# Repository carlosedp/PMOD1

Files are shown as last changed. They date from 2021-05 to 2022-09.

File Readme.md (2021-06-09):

# PMOD1 - RingPush module

This repository hosts all data related to PMOD1, a PMOD module with a LED ring and a rotary encoder with push button. Always use the latest version of the PCB.

## PCB 3D View:

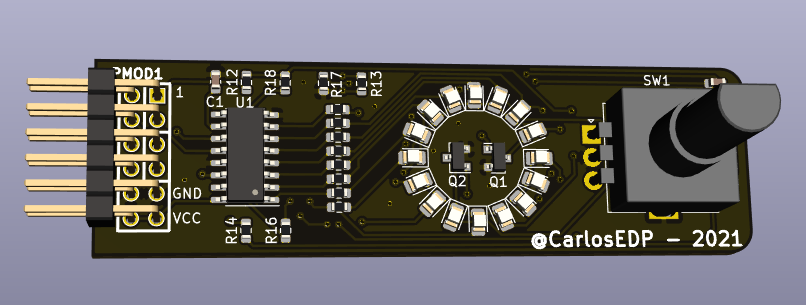
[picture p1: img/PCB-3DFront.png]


## Schematic

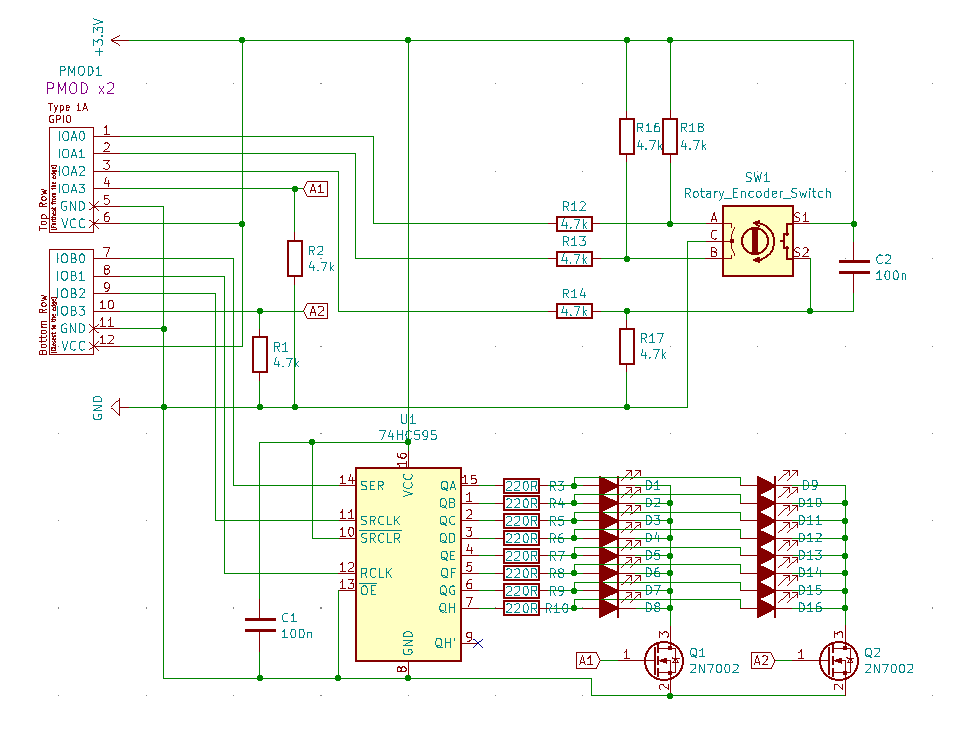
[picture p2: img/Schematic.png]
schematic


## BOM

Id|Designator|Package|Quantity|Designation|
----|------------|---------|----------|-------------|
1|U1|SOIC-16_3.9x9.9mm_P1.27mm|1|74HC595|||
2|PMOD1|pmod_pin_array_6x2|1|PMOD-Device-x2-Type-1A-GPIO|||
3|SW1|RotaryEncoder_Alps_EC11E-Switch_Vertical_H20mm|1|Rotary_Encoder_Switch|||
4|R1,R2,R12,R13,R14,R16,R17,R18|R_0603_1608Metric_Pad0.98x0.95mm_HandSolder|8|4.7k|||
5|C1,C2|C_0603_1608Metric_Pad1.08x0.95mm_HandSolder|2|100n|||
6|D1,D2,D3,D4,D5,D6,D7,D8,D9,D10,D11,D12,D13,D14,D15,D16|LED_0805_2012Metric_Pad1.15x1.40mm_HandSolder|16|LED_ALT|||
7|R3,R4,R5,R6,R7,R8,R9,R10|R_0603_1608Metric_Pad0.98x0.95mm_HandSolder|8|220R|||
8|Q1,Q2|SOT-23|2|2N7002|||

The repository has the following data:

* Kicad project with [schematic and PCB](Kicad-RingPush)
* [Arduino sample](arduino/RingLed/RingLed.ino) implemented on the NodeMCU board showing the encoder and rindLED functionality

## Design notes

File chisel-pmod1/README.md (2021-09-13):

# PMOD1 - Rotary Encoder and RingLed PMOD

This is a project built with Chisel HDL for the PMOD1, a Rotary Encoder and RingLED PMOD.

The Chisel sources uses a `-board` parameter to define which board is used and generate the proper PLL and build. To support this, an utility module was created.

## Building

The project provides two building methods. The first and recommended is using [Fusesoc](https://github.com/olofk/fusesoc), a package manager that handles all board backend files and configuration. It also makes adding support to new boards and vendors much easier.

A second method is using the built-in Makefile that generates the output Verilog code that can be imported into the board EDA manually.

### Fusesoc build and generation

<details>
  <summary>Installing FuseSOC</summary>

To install Fusesoc (requires Python3 and pip3):

```sh
pip3 install --upgrade --user fusesoc
```

Check if it's working:

```sh
$ fusesoc --version
1.12.0
```

If the terminal reports an error about the command not being found check that the directory `~/.local/bin` is in your command search path (`export PATH=~/.local/bin:$PATH`).

</details>

Fusesoc allows multiple boards from different vendors to be supported by the project. It uses chisel-generator to generate Verilog from Scala sources and calls the correct board EDA backend to create it's project files.

For example, to generate the programming files for the **ULX3s** board based on Lattice ECP5:

```sh
mkdir fusesoc-pmod1 && cd fusesoc-pmod1

fusesoc library add fusesoc-cores https://github.com/fusesoc/fusesoc-cores

# Since this project is not a standalone repo (but a folder in an umbrella repo)
# We clone it locally and add the library as a local dir.
git clone https://github.com/carlosedp/PMOD1
fusesoc library add pmod1 $(pwd)/PMOD1/chisel-pmod1

fusesoc run --target=ulx3s_85 carlosedp:demo:pmod1

# This requires all FPGA Toolchain applications to be installed locally, keep reading for a portable solution using containers
...
# Output bitstream will be on build/carlosedp_demo_chiselblinky_0/ulx3s_85-trellis
❯ ll build/carlosedp_demo_chiselblinky_0/ulx3s_85-trellis
total 2.7M
-rw-r--r-- 1 cdepaula staff  774 Apr  7 18:53 carlosedp_demo_chiselblinky_0.eda.yml
-rw-r--r-- 1 cdepaula staff  545 Apr  7 18:53 carlosedp_demo_chiselblinky_0.tcl
-rw-r--r-- 1 cdepaula staff  435 Apr  7 18:53 carlosedp_demo_chiselblinky_0.mk
-rw-r--r-- 1 cdepaula staff  608 Apr  7 18:53 Makefile
-rw-r--r-- 1 cdepaula staff 9.5K Apr  7 18:53 carlosedp_demo_chiselblinky_0.blif
-rw-r--r-- 1 cdepaula staff 655K Apr  7 18:53 carlosedp_demo_chiselblinky_0.json
-rw-r--r-- 1 cdepaula staff  44K Apr  7 18:53 carlosedp_demo_chiselblinky_0.edif
-rw-r--r-- 1 cdepaula staff  45K Apr  7 18:53 yosys.log
-rw-r--r-- 1 cdepaula staff 8.7K Apr  7 18:53 next.log
-rw-r--r-- 1 cdepaula staff 1.9M Apr  7 18:53 carlosedp_demo_chiselblinky_0.bit
```

Just program it to your FPGA with `OpenOCD` or in ULX3S case, [`ujprog`](https://github.com/f32c/tools/tree/master/ujprog)

### Building on containers

The standard build process uses locally installed tools like Java (for Chisel generation), Yosys, NextPNR, Vivado and others. Fusesoc also supports building the complete workflow by using containers thru a command launcher.

To use it:

```sh
# Download the command wrapper
wget https://gist.github.com/carlosedp/c0e29d55e48309a48961f2e3939acfe9/raw/bfeb1cfe2e188c1d5ced0b09aabc9902fdfda6aa/runme.py
chmod +x runme.py

# Run fusesoc with the wrapper as an environment var
EDALIZE_LAUNCHER=$(realpath ./runme.py) fusesoc run --target=ulx3s_85 carlosedp:demo:pmod1

# The output files will be on the local ./build dir like before
# Programming instructions will be printed-out.
```

### Adding support to new boards

<details>
  <summary>Click to expand</summary>

Support for new boards can be added in the `pmod1.core` file and programming instructions in the `proginfo/buildconfig.yaml` together with a board template text.

Three sections are required:

#### Fileset

Filesets lists the dependency from the chisel-generator, that outputs Verilog from Chisel (Scala) code. It also contains the static files used for each board like constraints and programming config that must be copied to the output project dir and used by EDA. The programming info text template is also added.

```yaml
  ulx3s-85:
    depend: ["fusesoc:utils:generators:0.1.6"]
    files:
      - constraints/ecp5-ulx3s.lpf: { file_type: LPF }
      - openocd/ft231x.cfg: { file_type: user }
      - openocd/LFE5U-85F.cfg: { file_type: user }
      - proginfo/ulx3s-template.txt: { file_type: user }
```

#### Generate

The generator section contains the Chisel generator parameters. It has the arguments to be passed to Chisel (the board), the project name and the output files created by the generator to be used by the EDA.

```yaml
  ulx3s:
    generator: chisel
    parameters:
      extraargs: "-board ulx3s"
      chiselproject: toplevel
      copy_core: true
      output:
        files:
          - generated/Toplevel.v: { file_type: verilogSource }
          - generated/pll_ulx3s.v: { file_type: verilogSource }
```

#### Target

Finally the target section has the board information to be passed to the EDA tools. Parameters like the package/die or extra parameters to synthesis or PnR. This is highly dependent of the EDA backend. It's name is the one passed on the `--target=` param on FuseSoc. It also references the fileset and generate configs.

```yaml
  ulx3s_85:
    default_tool: trellis
    description: ULX3S 85k version
    filesets: [ulx3s-85, proginfo]
    generate: [ulx3s]
    hooks:
      post_run: [ulx3s-85f]
    tools:
      diamond:
        part: LFE5U-85F-6BG381C
      trellis:
        nextpnr_options: [--package, CABGA381, --85k]
    toplevel: Toplevel
```

#### Post-run script

If you desire to add a programming information text output after generating the bitstream files, add the board to the `scripts` section (and to it's target hooks) calling the proginfo.py with a board identifier that must match the `boardconfig.yaml` file in the `proginfo` dir.

```yaml
  artya7-35t:
    cmd : [python3, proginfo.py, artya7-35t]
```

The `boardconfig.yaml` file must contain the files names used by each board and a corresponding template `.txt` file that will contain the output text. This will be printed after bitstream generation.

</details>

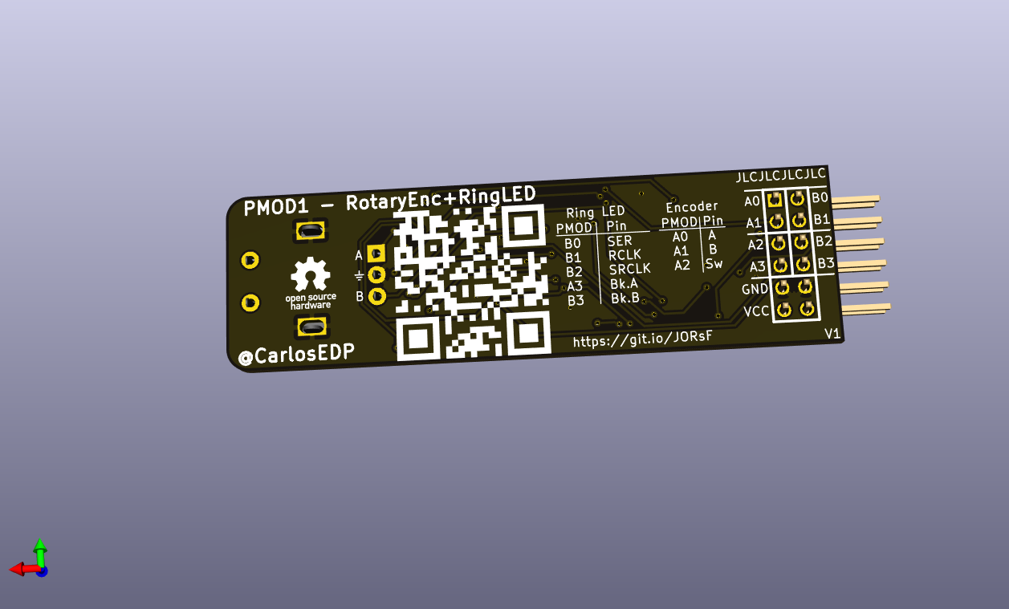
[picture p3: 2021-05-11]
Kicad-RingPush/V1.1/3D-RingPush-PMOD-Back.png

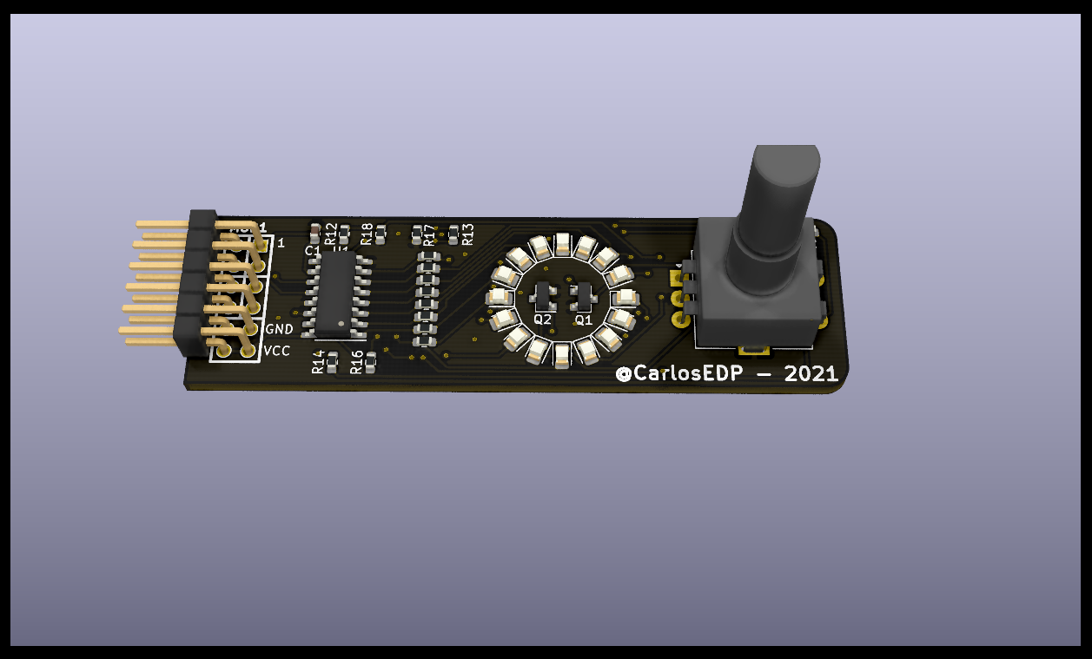
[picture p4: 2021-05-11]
Kicad-RingPush/V1.1/3D-RingPush-PMOD-Front.png

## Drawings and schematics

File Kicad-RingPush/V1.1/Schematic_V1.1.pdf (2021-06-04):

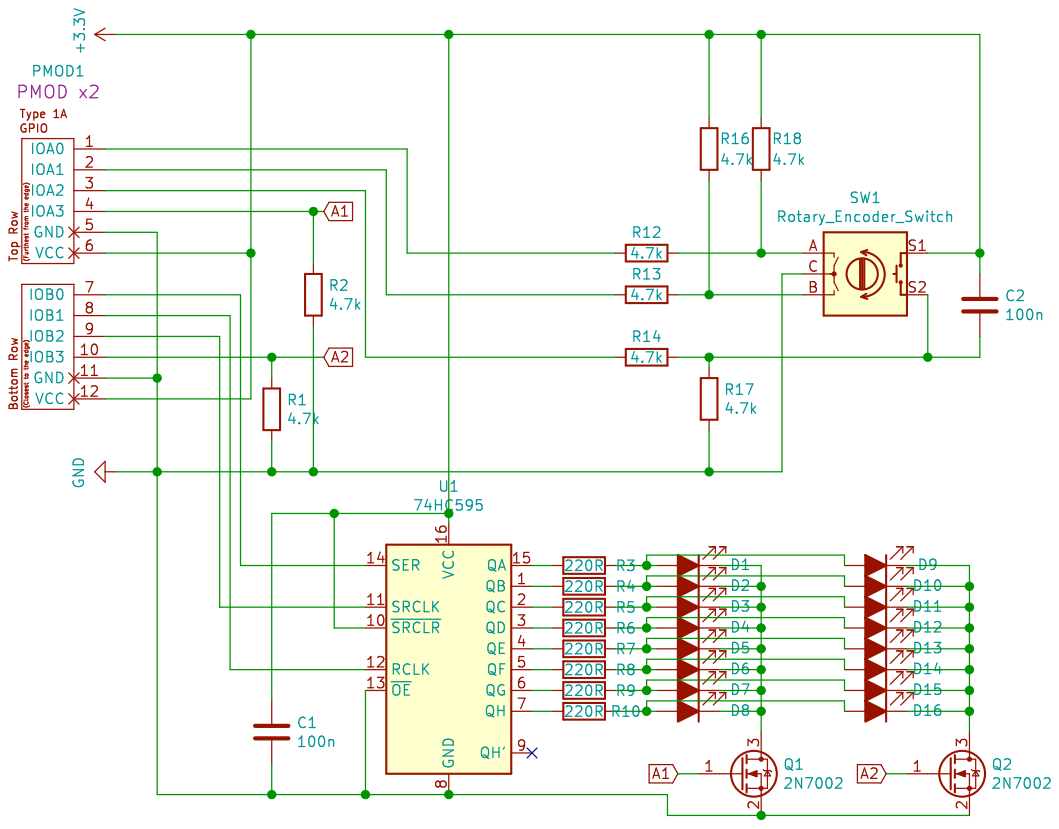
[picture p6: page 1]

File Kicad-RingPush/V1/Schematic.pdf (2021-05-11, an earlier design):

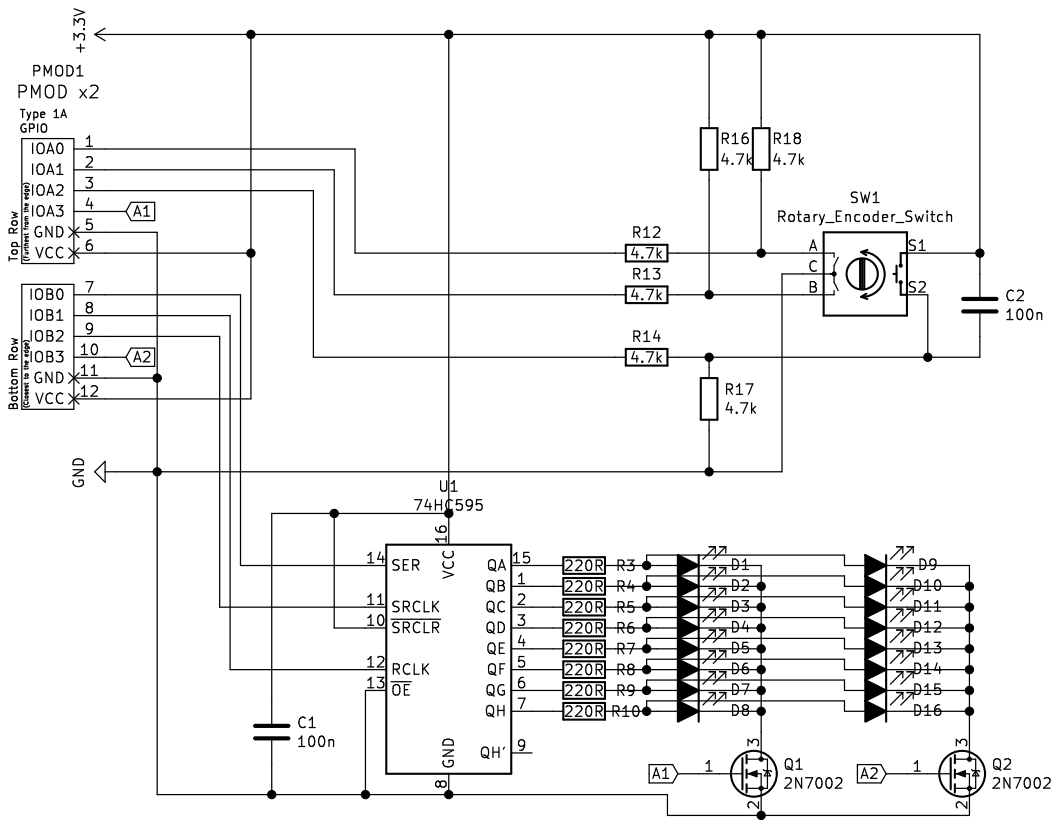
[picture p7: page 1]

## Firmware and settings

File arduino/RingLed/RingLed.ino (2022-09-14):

// Using ESP32-C3 NodeMCU pins
// RingLED Pins

const int dataPin = 6;   //Outputs the byte to transfer (Ser)
const int loadPin = 7;   //Controls the internal transference of data in SN74HC595 internal registers (RClk)
const int clockPin = 8;  //Generates the clock signal to control the transference of data (SRClk)
const int BankA = 18;     // Selects BankA - LEDs 1-8
const int BankB = 19;     // Selects BankB - LEDs 9-16
long interval = 200;

// Encoder Pins
int encoder0PinA = 1;
int encoder0PinB = 2;
int encoder0PinSW = 10;

int counter = 0;                    //Use this variable to store "steps"
int currentStateClock;              //Store the status of the clock pin (HIGH or LOW)
int lastStateClock;                 //Store the PREVIOUS status of the clock pin (HIGH or LOW)
String currentDir ="";              //Use this to print text 

void setup() {
  Serial.begin (115200);
  Serial.print("Starting up...");
  pinMode(dataPin, OUTPUT);
  pinMode(loadPin, OUTPUT);
  pinMode(clockPin, OUTPUT);
  pinMode(BankA, OUTPUT);
  pinMode(BankB, OUTPUT);
  // Set both banks to LOW as default since there is no pull-down resistors on V1 boards
  digitalWrite(BankA, LOW);
  digitalWrite(BankB, LOW);

  pinMode(encoder0PinA,INPUT_PULLUP);
  pinMode(encoder0PinB,INPUT_PULLUP);
  pinMode(encoder0PinSW, INPUT);

  lastStateClock = digitalRead(encoder0PinA);
}


unsigned long integerData = 1;
unsigned long total = 1;
void ringLED() {
  static long currentMillis;
  if (millis() - currentMillis >= interval) {
    if (total <=  128) {digitalWrite(BankA, HIGH);digitalWrite(BankB, LOW);}
    if (total >  128) {digitalWrite(BankA, LOW);digitalWrite(BankB, HIGH);}
    // Send data to IC
    digitalWrite(loadPin, LOW);
    shiftOut(dataPin, clockPin, LSBFIRST, integerData);
    digitalWrite(loadPin, HIGH);
    // Shift bits
    integerData = integerData << 1;
    total = total << 1;
    // Wrap around
    if (integerData > 128) {integerData = 1;}
    if (total > 65535) {total = 1;}
    currentMillis = millis();
   }
}

void rotEncoder() {
  currentStateClock = digitalRead(encoder0PinA);

  // If last and current state of Clock are different, then "pulse occurred"
  // React to only 1 state change to avoid double count
  if (currentStateClock != lastStateClock  && currentStateClock == 1){

    // If the Data state is different than the Clock state then
    // the encoder is rotating "CCW" so we decrement
    if (digitalRead(encoder0PinB) != currentStateClock) {
      counter --;
      currentDir ="Counterclockwise";
      interval --;
    } else {
      // Encoder is rotating CW so increment
      counter ++;
      currentDir ="Clockwise";
      interval ++;
    }

    Serial.print("Direction: ");
    Serial.print(currentDir);
    Serial.print(" | Counter: ");
    Serial.println(counter);
  }

  // We save last Clock state for next loop
  lastStateClock = currentStateClock;
}

void loop() {
  // Reset interval to default 200ms on button push
  if (digitalRead(encoder0PinSW) == HIGH) {
    interval = 200;
    Serial.print("Reset interval to: ");
    Serial.println(interval);
  }
  ringLED();
  rotEncoder();
}

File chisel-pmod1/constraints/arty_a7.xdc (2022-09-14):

# Clock pin
set_property PACKAGE_PIN E3 [get_ports {clock}]
set_property IOSTANDARD LVCMOS33 [get_ports {clock}]
# Clock constraints
create_clock -period 10.0 [get_ports {clock}]

# Buttons
set_property PACKAGE_PIN D9 [get_ports { reset }]
set_property IOSTANDARD LVCMOS33 [get_ports { reset }]
# set_property PACKAGE_PIN C9 [get_ports { b1 }]
# set_property IOSTANDARD LVCMOS33 [get_ports { b1 }]
# set_property PACKAGE_PIN B9 [get_ports { b2 }]
# set_property IOSTANDARD LVCMOS33 [get_ports { b2 }]
# set_property PACKAGE_PIN B8 [get_ports { b3 }]
# set_property IOSTANDARD LVCMOS33 [get_ports { b3 }]

# Slide Switches
# set_property PACKAGE_PIN A8 [get_ports { s0 }]
# set_property IOSTANDARD LVCMOS33 [get_ports { s0 }]
# set_property PACKAGE_PIN C11 [get_ports { s1 }]
# set_property IOSTANDARD LVCMOS33 [get_ports { s1 }]
# set_property PACKAGE_PIN C10 [get_ports { s2 }]
# set_property IOSTANDARD LVCMOS33 [get_ports { s2 }]
# set_property PACKAGE_PIN A10 [get_ports { s3 }]
# set_property IOSTANDARD LVCMOS33 [get_ports { s3 }]

# LEDs
set_property PACKAGE_PIN H5  [get_ports {led0}]
set_property PACKAGE_PIN J5  [get_ports {led1}]
# set_property PACKAGE_PIN T9  [get_ports {led2}]
# set_property PACKAGE_PIN T10  [get_ports {led3}]
set_property IOSTANDARD LVCMOS33 [get_ports {led0}]
set_property IOSTANDARD LVCMOS33 [get_ports {led1}]
# set_property IOSTANDARD LVCMOS33 [get_ports {led2}]
# set_property IOSTANDARD LVCMOS33 [get_ports {led3}]

# RGB LED 0
set_property PACKAGE_PIN G6  [get_ports {led2}]
set_property PACKAGE_PIN F6  [get_ports {led3}]
set_property PACKAGE_PIN E1  [get_ports {led4}]
set_property IOSTANDARD LVCMOS33 [get_ports {led2}]
set_property IOSTANDARD LVCMOS33 [get_ports {led3}]
set_property IOSTANDARD LVCMOS33 [get_ports {led4}]

# # RGB LED 1
set_property PACKAGE_PIN G3  [get_ports {led5}]
set_property PACKAGE_PIN J4  [get_ports {led6}]
# set_property PACKAGE_PIN G4  [get_ports {led6}]
set_property IOSTANDARD LVCMOS33 [get_ports {led5}]
set_property IOSTANDARD LVCMOS33 [get_ports {led6}]
# set_property IOSTANDARD LVCMOS33 [get_ports {led6}]

# # RGB LED 2
# set_property PACKAGE_PIN J3  [get_ports {led4}]
# set_property PACKAGE_PIN J2  [get_ports {led5}]
# set_property PACKAGE_PIN H4  [get_ports {led6}]
# set_property IOSTANDARD LVCMOS33 [get_ports {led4}]
# set_property IOSTANDARD LVCMOS33 [get_ports {led5}]
# set_property IOSTANDARD LVCMOS33 [get_ports {led6}]

# RGB LED 3
# set_property PACKAGE_PIN K1  [get_ports {led4}]
# set_property PACKAGE_PIN H6  [get_ports {led5}]
# set_property PACKAGE_PIN K2  [get_ports {led6}]
# set_property IOSTANDARD LVCMOS33 [get_ports {led4}]
# set_property IOSTANDARD LVCMOS33 [get_ports {led5}]
# set_property IOSTANDARD LVCMOS33 [get_ports {led6}]

## Pmod Header JA
# set_property -dict { PACKAGE_PIN G13   IOSTANDARD LVCMOS33 } [get_ports { PMOD0_A0 }]; #IO_0_15 Sch=ja[1]
# set_property -dict { PACKAGE_PIN B11   IOSTANDARD LVCMOS33 } [get_ports { PMOD0_A1 }]; #IO_L4P_T0_15 Sch=ja[2]
# set_property -dict { PACKAGE_PIN A11   IOSTANDARD LVCMOS33 } [get_ports { PMOD0_A2 }]; #IO_L4N_T0_15 Sch=ja[3]
# set_property -dict { PACKAGE_PIN D12   IOSTANDARD LVCMOS33 } [get_ports { PMOD0_A3 }]; #IO_L6P_T0_15 Sch=ja[4]
# set_property -dict { PACKAGE_PIN D13   IOSTANDARD LVCMOS33 } [get_ports { PMOD0_B0 }]; #IO_L6N_T0_VREF_15 Sch=ja[7]
# set_property -dict { PACKAGE_PIN B18   IOSTANDARD LVCMOS33 } [get_ports { PMOD0_B1 }]; #IO_L10P_T1_AD11P_15 Sch=ja[8]
# set_property -dict { PACKAGE_PIN A18   IOSTANDARD LVCMOS33 } [get_ports { PMOD0_B2 }]; #IO_L10N_T1_AD11N_15 Sch=ja[9]
# set_property -dict { PACKAGE_PIN K16   IOSTANDARD LVCMOS33 } [get_ports { PMOD0_B3 }]; #IO_25_15 Sch=ja[10]

## Pmod Header JB
set_property -dict { PACKAGE_PIN E15   IOSTANDARD LVCMOS33 } [get_ports { PMOD1_A0 }]; #IO_L11P_T1_SRCC_15 Sch=jb_p[1]
set_property -dict { PACKAGE_PIN E16   IOSTANDARD LVCMOS33 } [get_ports { PMOD1_A1 }]; #IO_L11N_T1_SRCC_15 Sch=jb_n[1]
set_property -dict { PACKAGE_PIN D15   IOSTANDARD LVCMOS33 } [get_ports { PMOD1_A2 }]; #IO_L12P_T1_MRCC_15 Sch=jb_p[2]
set_property -dict { PACKAGE_PIN C15   IOSTANDARD LVCMOS33 } [get_ports { PMOD1_A3 }]; #IO_L12N_T1_MRCC_15 Sch=jb_n[2]
set_property -dict { PACKAGE_PIN J17   IOSTANDARD LVCMOS33 } [get_ports { PMOD1_B0 }]; #IO_L23P_T3_FOE_B_15 Sch=jb_p[3]
set_property -dict { PACKAGE_PIN J18   IOSTANDARD LVCMOS33 } [get_ports { PMOD1_B1 }]; #IO_L23N_T3_FWE_B_15 Sch=jb_n[3]
set_property -dict { PACKAGE_PIN K15   IOSTANDARD LVCMOS33 } [get_ports { PMOD1_B2 }]; #IO_L24P_T3_RS1_15 Sch=jb_p[4]
set_property -dict { PACKAGE_PIN J15   IOSTANDARD LVCMOS33 } [get_ports { PMOD1_B3 }]; #IO_L24N_T3_RS0_15 Sch=jb_n[4]
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

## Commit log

2021-05-11 Initial import
    [RingPush-PMOD-B_Cu.gbl, RingPush-PMOD-B_Mask.gbs, RingPush-PMOD-B_Paste.gbp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]
2021-05-11 Add libs
    [RingPush-PMOD.sch]
2021-06-04 Add RingLED Arduino demo
2021-06-04 PCB V1.1
    This version addresses some issues found on V1 boards:
    - Add pull-down resistors to BankA/B selectors
    - Change 0603 pads from resistors, caps and LEDs to "handsolder" versions
    - Adjust some silk positions
    [RingPush-PMOD-B_Cu.gbl, RingPush-PMOD-B_Mask.gbs, RingPush-PMOD-B_Paste.gbp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]
2021-06-09 Add BOM and update schematic and readme
    [BOM-RingPush-PMOD.csv, RingPush-PMOD.kicad_pcb]
2021-06-09 Update Arduino sample with encoder
2021-06-09 Use local library. Reset with pushbutton
    [RingLed.ino]
2021-09-13 Add Chisel (FPGA) sample code to interact with the PMOD
    [LFE5U-25F.cfg, LFE5U-45F.cfg, LFE5U-85F.cfg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]
2021-09-13 Add initial test for encoder. Improve test output for parser
2021-09-14 Add rotary encoder tests
2022-09-14 Use Mill. Fix Arty constraints
    [arty_a7.xdc]
2022-09-14 Use ESP32-C3 pinout
